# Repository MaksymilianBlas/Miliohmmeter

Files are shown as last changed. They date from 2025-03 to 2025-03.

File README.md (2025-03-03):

# Miliohmmeter
Miliohmmeter project, inspired by video on Learn Electronics Repair channel.
This is an adaptation of a project that has been shown on Learn Electronics Repair channel, link to original video:
https://www.youtube.com/watch?v=Sz1CqJltWEY
I wanted to replace the bulky PCB (that was designed by someone and posted on PCBway projects page) with my own design, with SMD parts and better layout. The project was made in KiCad.
Additionally, a linear power supply has been integrated onto the PCB.
The PCBA with a suitable transformer has been placed in a small project case, with banana sockets and a 5-digit display.
Along the way, there have been some issues caused by counterfit OP07 op-amps from aliexpress.
The weakpoint of the project are the home-made poor-mans kelvin connection probes, because the tip is soldered together and is neither sharp enough or resistant to oxidation enough to guarantee a long problem-free and pleasant usage. The leads were not updated due to high cost and lost interest.

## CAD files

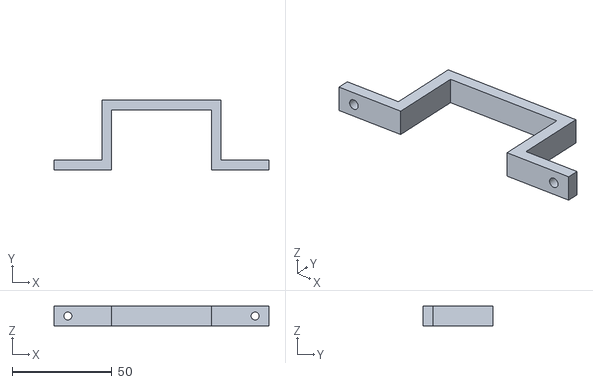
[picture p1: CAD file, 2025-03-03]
Trafholder.stl
108.0 x 35.0 x 10.0

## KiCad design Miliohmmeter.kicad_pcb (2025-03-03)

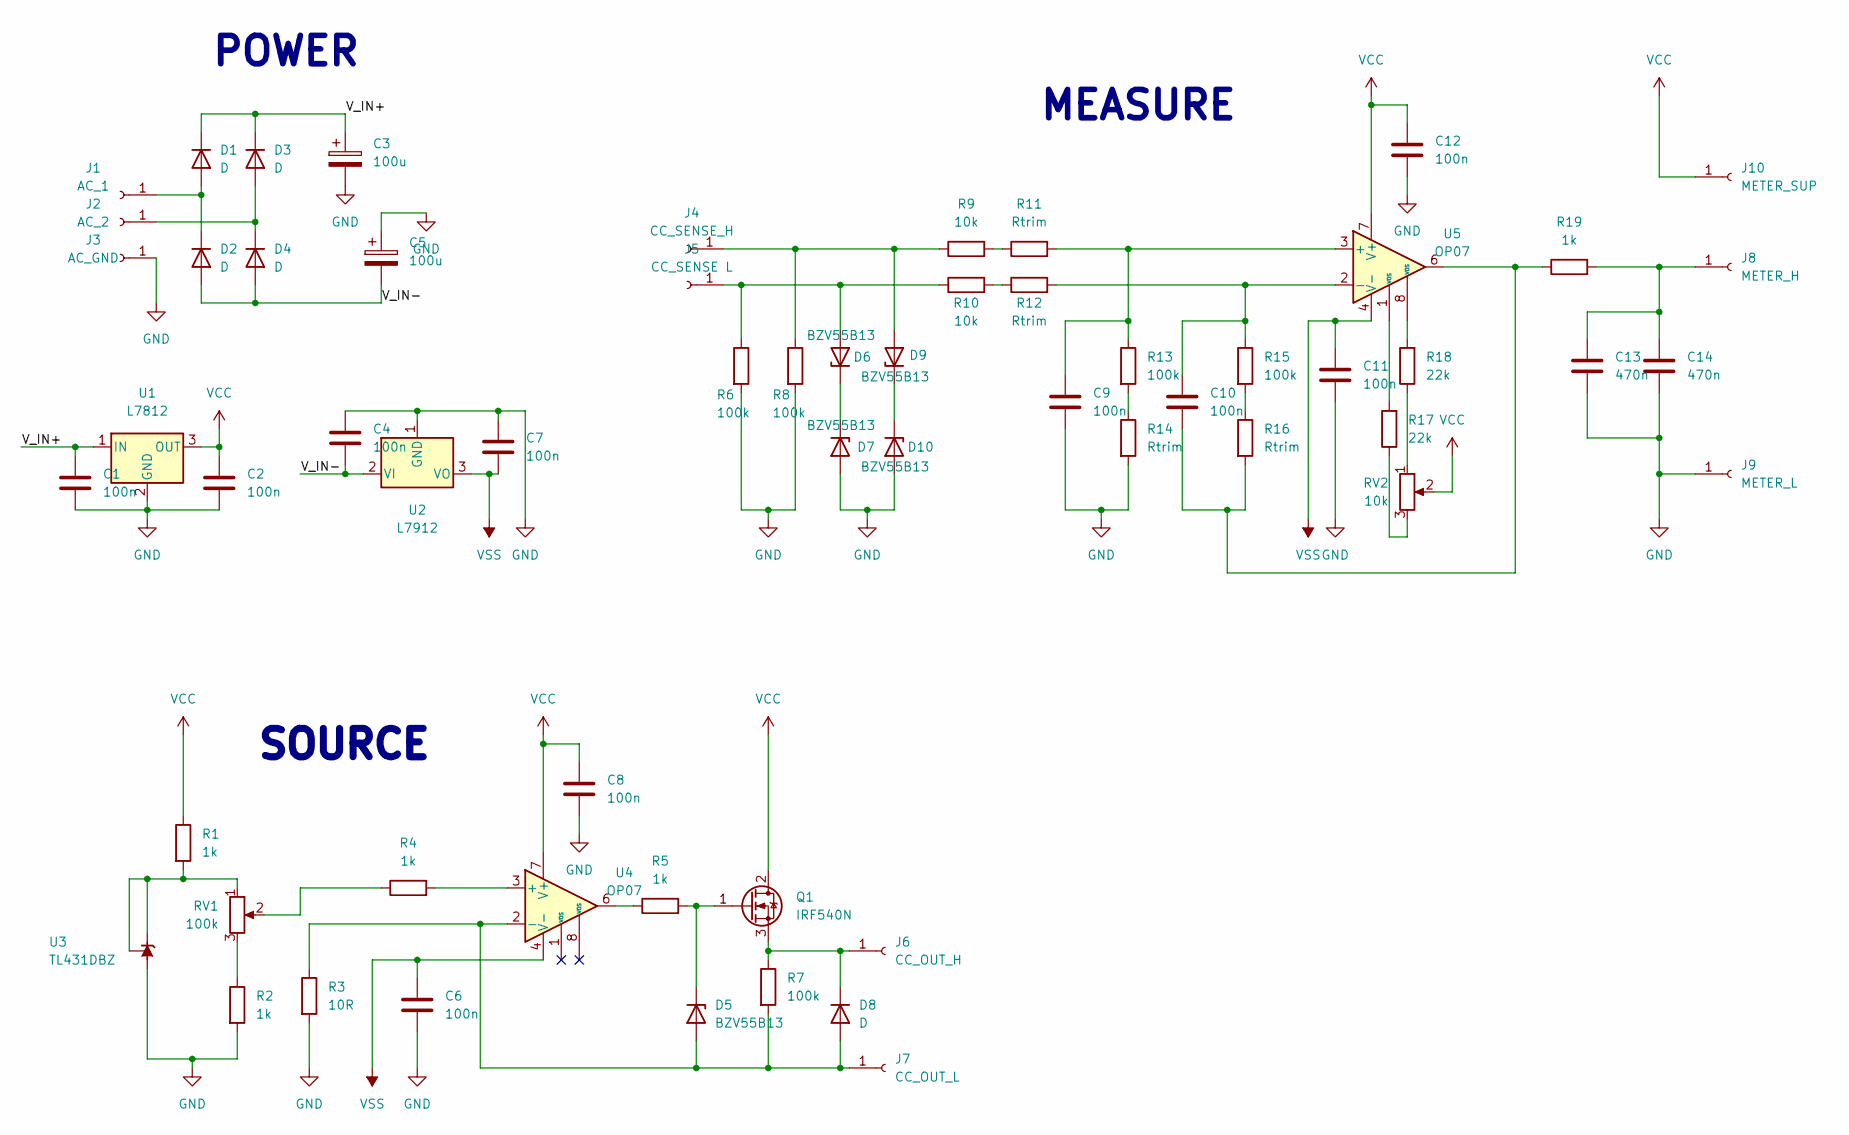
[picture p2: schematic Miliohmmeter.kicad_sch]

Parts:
C1, C2, C4, C6, C7, C8, C9, C10, C11, C12: 100n; C_0603_1608Metric_Pad1.08x0.95mm_HandSolder
C3, C5: 100u; CAP_EEETP1J102M
C13, C14: 470n; C_0805_2012Metric_Pad1.18x1.45mm_HandSolder
D1, D2, D3, D4, D8: D; D_SMA_Handsoldering
D5, D6, D7, D9, D10: BZV55B13; D_MiniMELF
J1: AC_1; SolderWire-0.75sqmm_1x01_D1.25mm_OD3.5mm
J2: AC_2; SolderWire-0.75sqmm_1x01_D1.25mm_OD3.5mm
J3: AC_GND; SolderWire-0.75sqmm_1x01_D1.25mm_OD3.5mm
J4: CC_SENSE_H; SolderWire-0.75sqmm_1x01_D1.25mm_OD3.5mm
J5: CC_SENSE L; SolderWire-0.75sqmm_1x01_D1.25mm_OD3.5mm
J6: CC_OUT_H; SolderWire-0.75sqmm_1x01_D1.25mm_OD3.5mm
J7: CC_OUT_L; SolderWire-0.75sqmm_1x01_D1.25mm_OD3.5mm
J8: METER_H; SolderWire-0.75sqmm_1x01_D1.25mm_OD3.5mm
J9: METER_L; SolderWire-0.75sqmm_1x01_D1.25mm_OD3.5mm
J10: METER_SUP; SolderWire-0.75sqmm_1x01_D1.25mm_OD3.5mm
Q1: IRF540N; TO-252-2
R1, R2, R4, R5, R19: 1k; R_0603_1608Metric_Pad0.98x0.95mm_HandSolder
R3: 10R; R_0805_2012Metric_Pad1.20x1.40mm_HandSolder
R6, R7, R8, R13, R15: 100k; R_0603_1608Metric_Pad0.98x0.95mm_HandSolder
R9, R10: 10k; R_0603_1608Metric_Pad0.98x0.95mm_HandSolder
R11, R12, R14, R16: Rtrim; R_0603_1608Metric_Pad0.98x0.95mm_HandSolder
R17, R18: 22k; R_0603_1608Metric_Pad0.98x0.95mm_HandSolder
RV1: 100k; Potentiometer_Bourns_3296W_Vertical
RV2: 10k; Potentiometer_Bourns_3296W_Vertical
U1: L7812; TO-252-2
U2: L7912; TO-252-2
U3: TL431DBZ; SOT-23_Handsoldering
U4, U5: OP07; SOIC-8_3.9x4.9mm_P1.27mm

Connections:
/V_IN+: C1.1, C3.1, D1.1 (K), D3.1 (K), U1.1 (IN)
/V_IN-: C4.2, C5.2, D2.2 (A), D4.2 (A), U2.2 (VI)
GND: C1.2, C2.2, C3.2, C4.1, C5.1, C6.2, C7.1, C8.2, C9.2, C11.2, C12.2, C13.2, C14.2, D7.2 (A), D10.2 (A), J3.1, J9.1, R2.2, R3.2, R6.2, R8.2, R14.2, U1.2 (GND), U2.1 (GND), U3.3 (A)
unnamed: C9.1, R11.2, R13.1, U5.3 (+)
unnamed: C10.1, R12.2, R15.1, U5.2 (-)
unnamed: C10.2, R16.2, R19.1, U5.6
unnamed: C13.1, C14.1, J8.1, R19.2
unnamed: D1.2 (A), D2.1 (K), J1.1
unnamed: D3.2 (A), D4.1 (K), J2.1
unnamed: D5.1 (K), Q1.1 (G), R5.2
unnamed: D5.2 (A), D8.2 (A), J7.1, R3.1, R7.2, U4.2 (-)
unnamed: D6.1 (K), D7.1 (K)
unnamed: D6.2 (A), J5.1, R6.1, R10.1
unnamed: D8.1 (K), J6.1, Q1.3 (S), R7.1
unnamed: D9.2 (A), J4.1, R8.1, R9.1
unnamed: D9.1 (K), D10.1 (K)
unnamed: R1.2, RV1.1, U3.1 (K), U3.2 (REF)
unnamed: R2.1, RV1.3
unnamed: R4.1, RV1.2
unnamed: R4.2, U4.3 (+)
unnamed: R5.1, U4.6
unnamed: R10.2, R12.1
unnamed: R9.2, R11.1
unnamed: R13.2, R14.1
unnamed: R15.2, R16.1
unnamed: R17.1, RV2.3
unnamed: R17.2, U5.1 (VOS)
unnamed: R18.1, RV2.1
unnamed: R18.2, U5.8 (VOS)
VCC: C2.1, C8.1, C12.1, J10.1, Q1.2 (D), R1.1, RV2.2, U1.3 (OUT), U4.7 (V+), U5.7 (V+)
VSS: C6.1, C7.2, C11.1, U2.3 (VO), U4.4 (V-), U5.4 (V-)

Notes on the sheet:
MEASURE
SOURCE
POWER

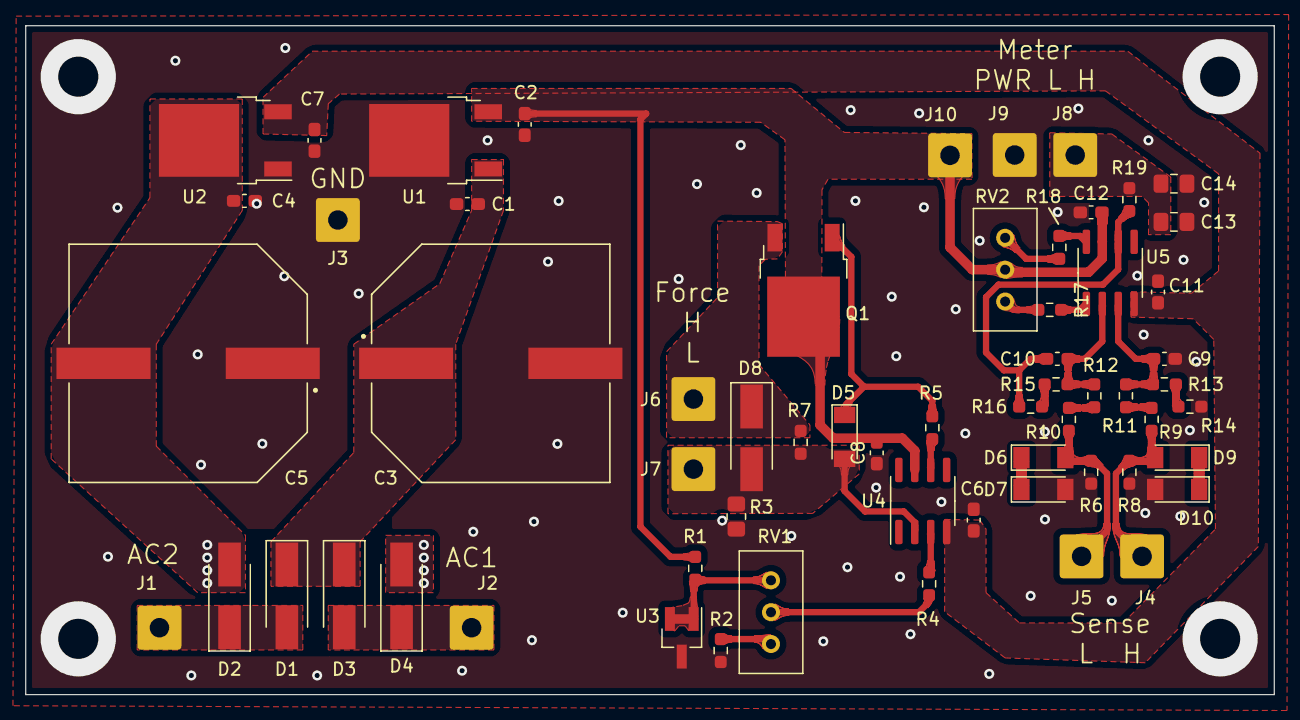
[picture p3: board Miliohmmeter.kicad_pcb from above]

Board: 2 copper layers, 99.6 x 53.3 mm, 61 parts (0 on the bottom side), 31 nets.

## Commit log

2025-03-03 Add files via upload
    Added KiCad project files and .stl model for a transformator holder for the project case.
    [Miliohmmeter.kicad_pcb, Miliohmmeter.kicad_sch, Trafholder.stl]
2025-03-03 Update README.md
    Added note about KiCad.
